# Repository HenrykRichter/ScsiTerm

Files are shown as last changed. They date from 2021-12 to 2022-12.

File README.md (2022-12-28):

# SCSITerm 08-15 

This project is a design of an active SCSI terminator for DB-25 ports.

## Pictures

The picture below shows Revision3 of the board.
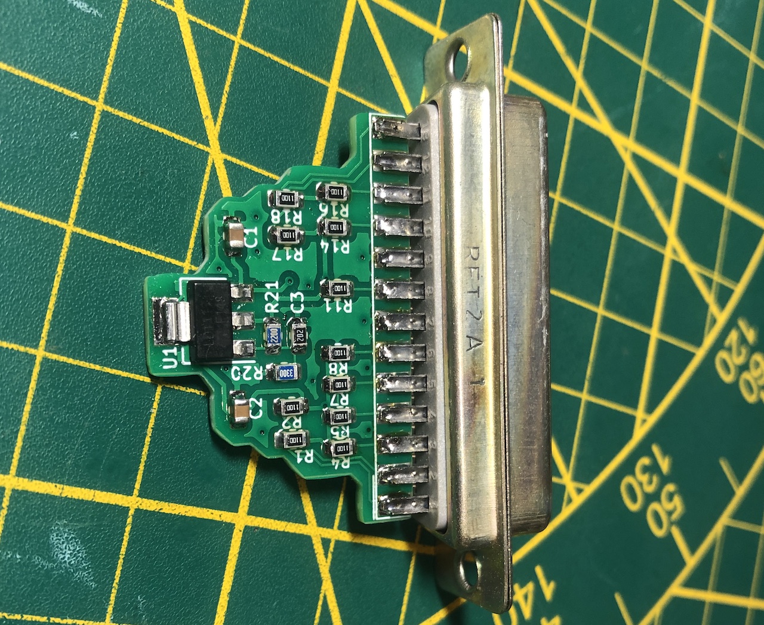
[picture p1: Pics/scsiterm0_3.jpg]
front view


## Parts list
- 1  DB-25 male (solder cup)
- 1  Voltage regulator SOT-223 LD1117 SC-R (or similar)
- 18 Resistors 110R 0805
- 1  Resistor 680R 0805 (R19, optional)
- 1  LED 0805 (optional)
- 3  Capacitors 10uF 0805
- 1  Resistor 220R 0805 (R21)
- 1  Resistor 330R 0805 (R20)
- 1  Resistor 2k 0805 (C3, instead of a previously planned capacitor for accurate 2.85V)

## Building and installation notes
Soldering should be straightforward for the SMD components and the DB-25 connector. Please don't forget the resistors on the underside of the PCB.

The PCB was designed with typical DB-25 shells in mind to be used as enclosure. Nevertheless, a custom case design for 3D printing is part of the repository. Just print the design twice and fasten it using M2.5 x 10 cylindrical screws and matching nuts.

## License

The material in this project may be used under the terms of the Attribution-NonCommercial-ShareAlike 4.0 International creative commons license. Please refer to https://creativecommons.org/licenses/by-nc-sa/4.0/ for details or see the LICENSE file in this repository.

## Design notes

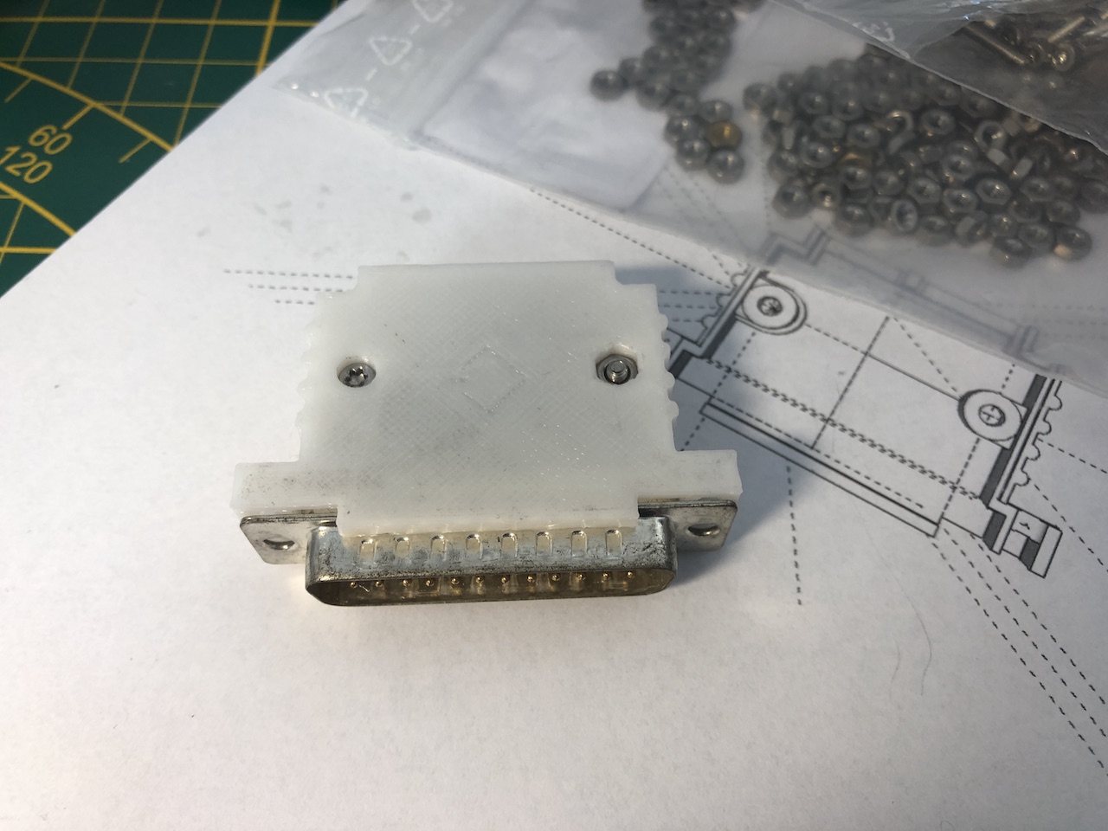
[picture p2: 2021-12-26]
Pics/scsiterm_shell.jpg

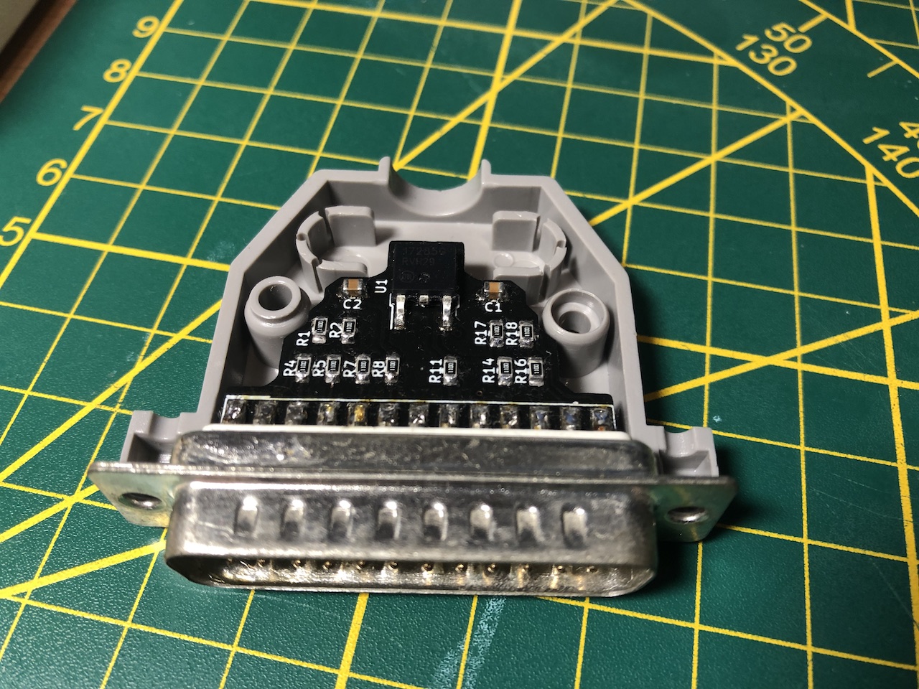
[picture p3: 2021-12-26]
Pics/scsiterm_front.jpg

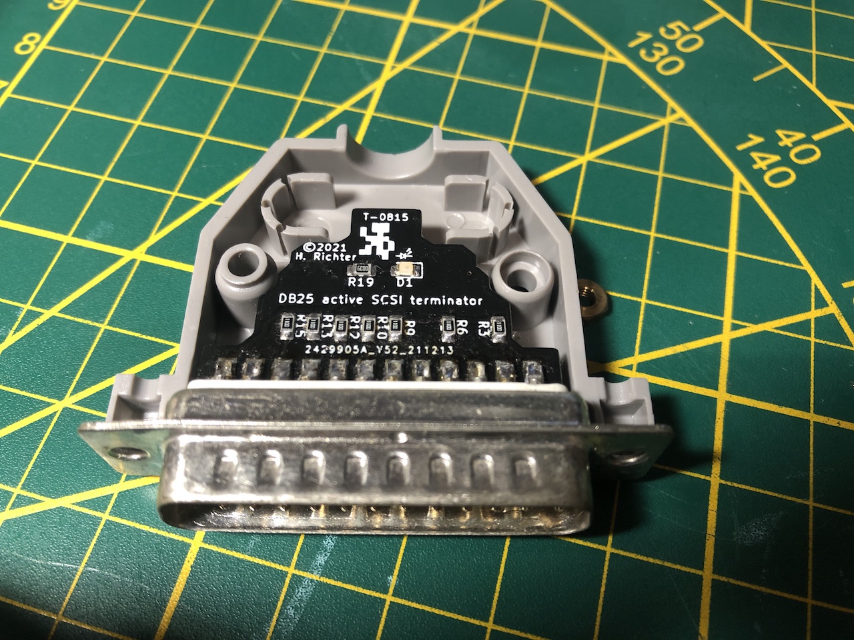
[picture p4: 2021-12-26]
Pics/scsiterm_back.jpg

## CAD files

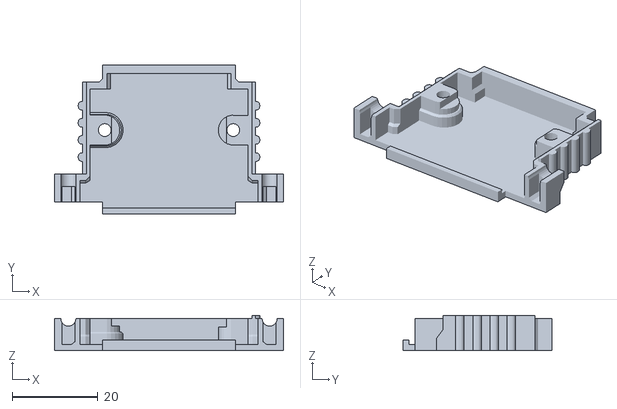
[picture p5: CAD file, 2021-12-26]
SCSITerm.stl
53.5 x 34.8 x 8.30

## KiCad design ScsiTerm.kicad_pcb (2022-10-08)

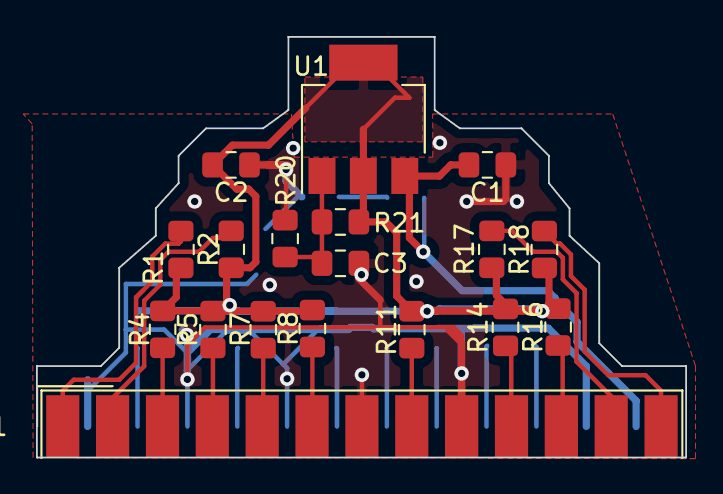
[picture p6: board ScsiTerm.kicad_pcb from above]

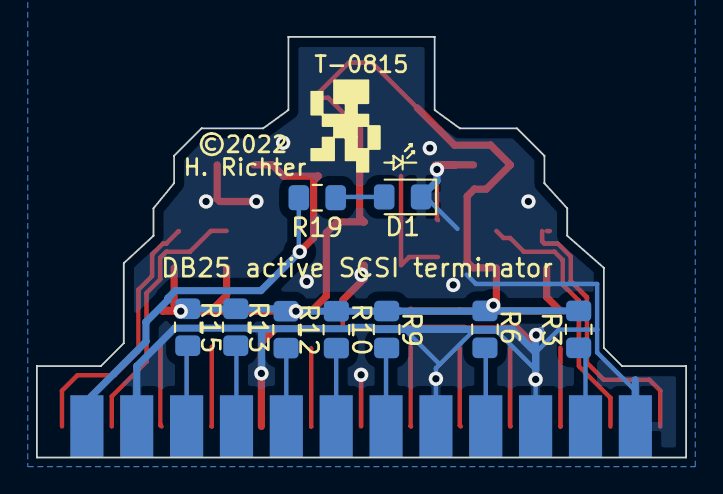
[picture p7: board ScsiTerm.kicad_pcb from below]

Board: 2 copper layers, 36.1 x 23.4 mm, 27 parts (9 on the bottom side), 23 nets.

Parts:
C1, C2: 10uF; C_0805_2012Metric_Pad1.15x1.40mm_HandSolder
C3: 4.7uF; C_0805_2012Metric_Pad1.15x1.40mm_HandSolder
D1: LED; LED_0805_2012Metric_Pad1.15x1.40mm_HandSolder
J1: DB25_Male; DSUB-25_Male_EdgeMount_P2.77mm
R1, R2, R3, R4, R5, R6, R7, R8, R9, R10, R11, R12, R13, R14, R15, R16, R17, R18: 110; R_0805_2012Metric_Pad1.15x1.40mm_HandSolder
R19: 680; R_0805_2012Metric_Pad1.15x1.40mm_HandSolder
R20: 150; R_0805_2012Metric_Pad1.15x1.40mm_HandSolder
R21: 120; R_0805_2012Metric_Pad1.15x1.40mm_HandSolder
U1: LD1117 SC-R; SOT-223-3_TabPin2

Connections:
+5V: C1.1, J1.25, R19.2, U1.3
/2.85V: C2.1, R1.1, R2.1, R3.1, R4.1, R5.1, R6.1, R7.1, R8.1, R9.1, R10.2, R11.2, R12.2, R13.2, R14.2, R15.2, R16.2, R17.2, R18.2, R21.2, U1.2
/ACK: J1.5, R7.2
/ATN: J1.17, R6.2
/BSY: J1.6, R8.2
/C_D: J1.15, R3.2
/DB0: J1.8, R11.1
/DB1: J1.21, R12.1
/DB2: J1.22, R13.1
/DB3: J1.10, R14.1
/DB4: J1.23, R15.1
/DB5: J1.11, R16.1
/DB6: J1.12, R17.1
/DB7: J1.13, R18.1
/DBP: J1.20, R10.1
/I_O: J1.3, R4.2
/MSG: J1.2, R2.2
/REQ: J1.1, R1.2
/RST: J1.4, R5.2
/SEL: J1.19, R9.2
GND: C1.2, C2.2, C3.2, D1.1, J1.7, J1.9, J1.14, J1.16, J1.18, J1.24, R20.1
unnamed: C3.1, R20.2, R21.1, U1.1
unnamed: D1.2, R19.1

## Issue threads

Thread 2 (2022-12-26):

readme doesn't show the footprint or output voltage of u1

ogg1e, 2022-12-26:
It would be nice if the readme had an example part # for u1, or the footprint and characteristics of U1.

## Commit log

2021-12-26 initial Git import
    [SCSITerm.stl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]
2022-10-08 Version 0.3: 2.85V regulator by adjustable variant This version will now use a more common voltage regulator since the 2.85V parts are going EOL.
    [ScsiTerm-B_Cu.gbl, ScsiTerm-B_Mask.gbs, ScsiTerm-B_SilkS.gbo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]

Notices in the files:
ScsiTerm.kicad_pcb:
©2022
